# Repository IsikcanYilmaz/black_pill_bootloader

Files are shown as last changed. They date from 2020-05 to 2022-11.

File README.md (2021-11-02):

~ L I G H T  C U B E ~

A "Cube of light" using panels full of WS2812B addressable LEDs, based on an STM32L453.

Current state of the project is:
 - LED panels glued and soldered into forming the 5 sides of the cube.
 - The panels work; STM devboard able to play animations and whatnot.
 - HW design should be done. Gotta order it
 
Need to do:
 - Order it, assemble it.
 - Get the nordic part to work, enable bluetooth. 

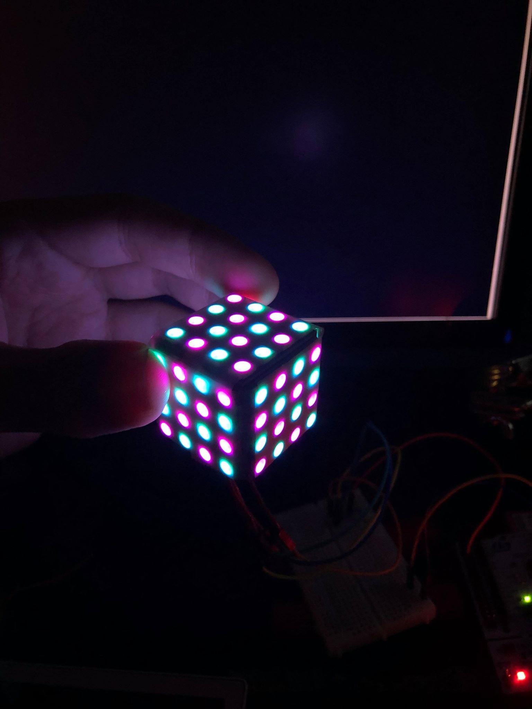
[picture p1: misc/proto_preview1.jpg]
Prototype 1


Prototype demo:
https://imgur.com/a/DEMgBDq

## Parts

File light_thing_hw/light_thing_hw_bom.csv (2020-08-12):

Id | Designator | Package | Quantity | Designation | Reference / name | Supplier | Notes | unit price | multiplier | total
1 | C6,C5 | C_0603_1608Metric_Pad1.05x0.95mm_HandSolder | 2 | 1uF | CL10A105KP8NNNC |  |  | 0.038 | 2 | 0.076
2 | C7,C19,C20 | C_0603_1608Metric_Pad1.05x0.95mm_HandSolder | 3 | 220uF | GRM31CC80G227ME11L |  |  | 1.29 | 3 | 3.87
3 | J5 | PinHeader_1x03_P1.00mm_Vertical | 1 | MIC_CONN | --- |  |  | 0 | 1 | 0
4 | U5A1 | LQFP-64-1EP_10x10mm_P0.5mm_EP6.5x6.5mm | 1 | STM32L452RETx | ?STM32L452RET6? |  |  | 7.1 | 1 | 7.1
5 | C1,C2,C3,C4,C16,C17 | C_0603_1608Metric_Pad1.05x0.95mm_HandSolder | 6 | 0.1uF | ?C0603C104Z3VACTU? |  |  | 0.031 | 6 | 0.186
6 | C8,C10,C14,C18 | C_0603_1608Metric_Pad1.05x0.95mm_HandSolder | 4 | 10uF | ?GRM188R61A106KE69J? |  |  | 0.148 | 4 | 0.592
7 | C9,C11,C13 | C_0603_1608Metric_Pad1.05x0.95mm_HandSolder | 3 | 100nF | C0603C104Z3VACTU |  |  | 0.031 | 3 | 0.093
8 | C12 | C_0603_1608Metric_Pad1.05x0.95mm_HandSolder | 1 | 1nF | ?CC0603KRX7R9BB102? |  |  | 0.1 | 1 | 0.1
9 | C15 | C_0603_1608Metric_Pad1.05x0.95mm_HandSolder | 1 | 2700pF | ?CC0603KRX7R9BB272? |  |  | 0.1 | 1 | 0.1
10 | D1 | D_SOD-323_HandSoldering | 1 | 2.5A, 20V | PMEG4030EP,115? |  |  | 0.43 | 1 | 0.43
11 | D2 | LED_0603_1608Metric_Pad1.05x0.95mm_HandSolder | 1 | GREEN LED | ?LTST-C191KRKT? |  |  | 0.26 | 1 | 0.26
12 | D3 | LED_0603_1608Metric_Pad1.05x0.95mm_HandSolder | 1 | RED LED | ?LTST-C191KRKT? |  |  | 0.26 | 1 | 0.26
13 | J1 | PinHeader_2x05_P1.00mm_Vertical | 1 | CONNECTORS | --- |  |  | 0 | 1 | 0
14 | J2 | Molex_PicoBlade_53261-0271_1x02-1MP_P1.25mm_Horizontal | 1 | Li-Ion Battery | ?0532610271? WM7620CT-ND? |  |  | 0.51 | 1 | 0.51
15 | J3 | PinHeader_2x02_P1.00mm_Vertical | 1 | ADDR_LED_PANEL_1_CONNECTORS | --- |  |  | 0 | 1 | 0
16 | J4 | PinHeader_2x02_P1.00mm_Vertical | 1 | ADDR_LED_PANEL_2_CONNECTORS | --- |  |  | 0 | 1 | 0
17 | L1 | L_0603_1608Metric_Pad1.05x0.95mm_HandSolder | 1 | 10uH, 2.5A | ?CBMF1608T100K? |  | this needs to change :( | 2.59333 | 1 | 2.59333
18 | Q1 | SOT-23 | 1 | MMBF170 | ?MMBF170LT1G? |  |  | 0.28 | 1 | 0.28
19 | R1,R2,R14,R17 | R_0603_1608Metric_Pad1.05x0.95mm_HandSolder | 4 | 1k | ?RC0603JR-071KL? |  |  | 0.018 | 4 | 0.072
20 | R3 | R_0603_1608Metric_Pad1.05x0.95mm_HandSolder | 1 | 30.1k | ?RT0603BRD0730K1L? |  |  | 0.35 | 1 | 0.35
21 | R4 | R_0603_1608Metric_Pad1.05x0.95mm_HandSolder | 1 | 10k | ?RC0603FR-0710KL? |  |  | 0.022 | 1 | 0.022
22 | R5 | R_0603_1608Metric_Pad1.05x0.95mm_HandSolder | 1 | 10K | ?RC0603FR-0710KL? |  |  | 0.022 | 1 | 0.022
23 | R6,R10,R11,R12,R13 | R_0603_1608Metric_Pad1.05x0.95mm_HandSolder | 5 | 4.7k | ?RC0603JR-074K7L? |  |  | 0.018 | 5 | 0.09
24 | R7 | R_0603_1608Metric_Pad1.05x0.95mm_HandSolder | 1 | 100 | ?RC0603FR-07100RL? |  |  | 0.022 | 1 | 0.022
25 | R8,R9 | R_0603_1608Metric_Pad1.05x0.95mm_HandSolder | 2 | 510 | ?RC0603FR-07510RL? |  |  | 0.022 | 2 | 0.044
26 | R15 | R_0603_1608Metric_Pad1.05x0.95mm_HandSolder | 1 | 2k | ?RC0603FR-072KL? |  |  | 0.022 | 1 | 0.022
27 | R16 | R_0603_1608Metric_Pad1.05x0.95mm_HandSolder | 1 | 357 | ?RC0603FR-07357RL? |  |  | 0.022 | 1 | 0.022
28 | SW1 | SW_SPST_B3U-3000P | 1 | ST_USER_BUTTON1 | EVP-AKE31A? |  |  | 0.61 | 1 | 0.61
29 | U1 | BC832-BC832_3d1 | 1 | BC832-V1 | 1914-1017-1-ND |  |  | 11.66 | 1 | 11.66
30 | U3 | MCP73833T-FCIUN-SMD | 1 | MCP73833T-FCI_UN | MCP73833T-FCI/UN? |  |  | 0.85 | 1 | 0.85
31 | U4 | SOT-23-5 | 1 | LMR62421XMF | LMR62421XMF/NOPB |  |  | 1.95 | 1 | 1.95
32 | U5 | LP38511MRX-ADJ_NOPB | 1 | LP38511MRX-ADJ_NOPB | LP38511MRX-ADJ/NOPB? |  |  | 1.77 | 1 | 1.77
33 | USB_MICRO_CONN1 | USB_Micro-B_Molex_47346-0001 | 1 | USB_OTG | ?0473461001? / WM11228CT-ND? |  |  | 0.91 | 1 | 0.91
34 | TP1,TP2 | TestPoint_Pad_D1.0mm | 2 | TestPoint | --- |  |  | 0 | 2 | 0
35 | U2 | LGA-14_3x2.5mm_P0.5mm_LayoutBorder3x4y_modded | 1 | LSM6DS3 | LSM6DS3TR? |  |  | 3.06 | 1 | 3.06
36 | R18 | R_0603_1608Metric_Pad1.05x0.95mm_HandSolder | 1 | 300 | ?RC0603FR-07300RL? |  |  | 0.022 | 1 | 0.022
37 | Q2 | SOT-23 | 1 | BSS83P | BSS83PH6327XTSA1 |  |  | 0.41 | 1 | 0.41
38 | SW2 | SW_SPST_EVPBF | 1 | ST_RESET_BUTTON |  |  |  | 0 | 1 | 0
 |  |  |  |  |  |  |  |  |  | 38.35833

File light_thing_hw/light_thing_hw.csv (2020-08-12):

Id | Designator | Package | Quantity | Designation | Supplier and ref
1 | U5A1 | LQFP-64-1EP_10x10mm_P0.5mm_EP6.5x6.5mm | 1 | STM32L452RETx
2 | C1,C2,C3,C4,C16,C17 | C_0603_1608Metric_Pad1.05x0.95mm_HandSolder | 6 | 0.1uF
3 | C5,C6 | C_0603_1608Metric_Pad1.05x0.95mm_HandSolder | 2 | 1uF
4 | C7 | C_0603_1608Metric_Pad1.05x0.95mm_HandSolder | 1 | C_Small
5 | C8,C10,C14,C18 | C_0603_1608Metric_Pad1.05x0.95mm_HandSolder | 4 | 10uF
6 | C9,C11,C13 | C_0603_1608Metric_Pad1.05x0.95mm_HandSolder | 3 | 100nF
7 | C12 | C_0603_1608Metric_Pad1.05x0.95mm_HandSolder | 1 | 1nF
8 | C15 | C_0603_1608Metric_Pad1.05x0.95mm_HandSolder | 1 | 2700pF
9 | D1 | D_SOD-323_HandSoldering | 1 | 2.5A, 20V
10 | D2 | LED_0603_1608Metric_Pad1.05x0.95mm_HandSolder | 1 | GREEN LED
11 | D3 | LED_0603_1608Metric_Pad1.05x0.95mm_HandSolder | 1 | RED LED
12 | J1 | PinHeader_2x05_P1.00mm_Vertical | 1 | CONNECTORS
13 | J2 | Molex_PicoBlade_53261-0271_1x02-1MP_P1.25mm_Horizontal | 1 | Li-Ion Battery
14 | J3 | PinHeader_2x02_P1.00mm_Vertical | 1 | ADDR_LED_PANEL_1_CONNECTORS
15 | J4 | PinHeader_2x02_P1.00mm_Vertical | 1 | ADDR_LED_PANEL_2_CONNECTORS
16 | L1 | L_0603_1608Metric_Pad1.05x0.95mm_HandSolder | 1 | 10uH, 2.5A
17 | Q1 | SOT-23 | 1 | MMBF170
18 | R1,R2,R14,R17 | R_0603_1608Metric_Pad1.05x0.95mm_HandSolder | 4 | 1k
19 | R3 | R_0603_1608Metric_Pad1.05x0.95mm_HandSolder | 1 | 30.1k
20 | R4 | R_0603_1608Metric_Pad1.05x0.95mm_HandSolder | 1 | 10k
21 | R5 | R_0603_1608Metric_Pad1.05x0.95mm_HandSolder | 1 | 10K
22 | R6,R10,R11,R12,R13 | R_0603_1608Metric_Pad1.05x0.95mm_HandSolder | 5 | 4.7k
23 | R7 | R_0603_1608Metric_Pad1.05x0.95mm_HandSolder | 1 | 100
24 | R8,R9 | R_0603_1608Metric_Pad1.05x0.95mm_HandSolder | 2 | 510
25 | R15 | R_0603_1608Metric_Pad1.05x0.95mm_HandSolder | 1 | 2k
26 | R16 | R_0603_1608Metric_Pad1.05x0.95mm_HandSolder | 1 | 357
27 | SW1 | SW_SPST_B3U-3000P | 1 | ST_USER_BUTTON1
28 | SW2 | SW_SPST_CK_RS282G05A3 | 1 | ST_RESET_BUTTON
29 | U1 | BC832-BC832_3d1 | 1 | BC832-V1
30 | U3 | MCP73833T-FCIUN-SMD | 1 | MCP73833T-FCI_UN
31 | U4 | SOT-23-5 | 1 | LMR62421XMF
32 | U5 | LP38511MRX-ADJ_NOPB | 1 | LP38511MRX-ADJ_NOPB
33 | USB_MICRO_CONN1 | USB_Micro-B_Molex_47346-0001 | 1 | USB_OTG
34 | 3v3,gnd | TestPoint_Pad_D1.0mm | 2 | TestPoint
35 | U2 | LGA-14_3x2.5mm_P0.5mm_LayoutBorder3x4y_modded | 1 | LSM6DS3

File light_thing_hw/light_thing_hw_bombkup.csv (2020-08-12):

Id | Designator | Package | Quantity | Designation | Reference / name | Supplier
1 | C6,C5 | C_0603_1608Metric_Pad1.05x0.95mm_HandSolder | 2 | 1uF | ‎CL10A105KP8NNNC‎
2 | C7 | C_0603_1608Metric_Pad1.05x0.95mm_HandSolder | 1 | 1000uF | ‎GRM31CC80G227ME11L‎
3 | J5 | PinHeader_1x03_P1.00mm_Vertical | 1 | MIC_CONN
4 | U5A1 | LQFP-64-1EP_10x10mm_P0.5mm_EP6.5x6.5mm | 1 | STM32L452RETx | ‎STM32L452RET6‎
5 | C1,C2,C3,C4,C16,C17 | C_0603_1608Metric_Pad1.05x0.95mm_HandSolder | 6 | 0.1uF | ‎C0603C104Z3VACTU‎
6 | C8,C10,C14,C18 | C_0603_1608Metric_Pad1.05x0.95mm_HandSolder | 4 | 10uF | ‎GRM188R61A106KE69J‎
7 | C9,C11,C13 | C_0603_1608Metric_Pad1.05x0.95mm_HandSolder | 3 | 100nF | C0603C104Z3VACTU
8 | C12 | C_0603_1608Metric_Pad1.05x0.95mm_HandSolder | 1 | 1nF | ‎CC0603KRX7R9BB102‎
9 | C15 | C_0603_1608Metric_Pad1.05x0.95mm_HandSolder | 1 | 2700pF | ‎CC0603KRX7R9BB272‎
10 | D1 | D_SOD-323_HandSoldering | 1 | 2.5A, 20V
11 | D2 | LED_0603_1608Metric_Pad1.05x0.95mm_HandSolder | 1 | GREEN LED
12 | D3 | LED_0603_1608Metric_Pad1.05x0.95mm_HandSolder | 1 | RED LED
13 | J1 | PinHeader_2x05_P1.00mm_Vertical | 1 | CONNECTORS
14 | J2 | Molex_PicoBlade_53261-0271_1x02-1MP_P1.25mm_Horizontal | 1 | Li-Ion Battery
15 | J3 | PinHeader_2x02_P1.00mm_Vertical | 1 | ADDR_LED_PANEL_1_CONNECTORS
16 | J4 | PinHeader_2x02_P1.00mm_Vertical | 1 | ADDR_LED_PANEL_2_CONNECTORS
17 | L1 | L_0603_1608Metric_Pad1.05x0.95mm_HandSolder | 1 | 10uH, 2.5A
18 | Q1 | SOT-23 | 1 | MMBF170 | ‎MMBF170LT1G‎
19 | R1,R2,R14,R17 | R_0603_1608Metric_Pad1.05x0.95mm_HandSolder | 4 | 1k
20 | R3 | R_0603_1608Metric_Pad1.05x0.95mm_HandSolder | 1 | 30.1k
21 | R4 | R_0603_1608Metric_Pad1.05x0.95mm_HandSolder | 1 | 10k
22 | R5 | R_0603_1608Metric_Pad1.05x0.95mm_HandSolder | 1 | 10K
23 | R6,R10,R11,R12,R13 | R_0603_1608Metric_Pad1.05x0.95mm_HandSolder | 5 | 4.7k
24 | R7 | R_0603_1608Metric_Pad1.05x0.95mm_HandSolder | 1 | 100
25 | R8,R9 | R_0603_1608Metric_Pad1.05x0.95mm_HandSolder | 2 | 510
26 | R15 | R_0603_1608Metric_Pad1.05x0.95mm_HandSolder | 1 | 2k
27 | R16 | R_0603_1608Metric_Pad1.05x0.95mm_HandSolder | 1 | 357
28 | SW1 | SW_SPST_B3U-3000P | 1 | ST_USER_BUTTON1 | EVP-AKE31A‎
29 | U1 | BC832-BC832_3d1 | 1 | BC832-V1
30 | U3 | MCP73833T-FCIUN-SMD | 1 | MCP73833T-FCI_UN | MCP73833T-FCI/UN‎ | digikey
31 | U4 | SOT-23-5 | 1 | LMR62421XMF | LMR62421XMF/NOPB | digikey
32 | U5 | LP38511MRX-ADJ_NOPB | 1 | LP38511MRX-ADJ_NOPB | LP38511MRX-ADJ/NOPB‎
33 | USB_MICRO_CONN1 | USB_Micro-B_Molex_47346-0001 | 1 | USB_OTG | ‎0473461001‎ / WM11228CT-ND‎
34 | TP1,TP2 | TestPoint_Pad_D1.0mm | 2 | TestPoint
35 | U2 | LGA-14_3x2.5mm_P0.5mm_LayoutBorder3x4y_modded | 1 | LSM6DS3 | ‎LSM6DS3TR‎
36 | R18 | R_0603_1608Metric_Pad1.05x0.95mm_HandSolder | 1 | 300
37 | Q2 | SOT-23 | 1 | BSS83P | ‎BSS83PH6327XTSA1‎
38 | SW2 | SW_SPST_EVPBF | 1 | ST_RESET_BUTTON

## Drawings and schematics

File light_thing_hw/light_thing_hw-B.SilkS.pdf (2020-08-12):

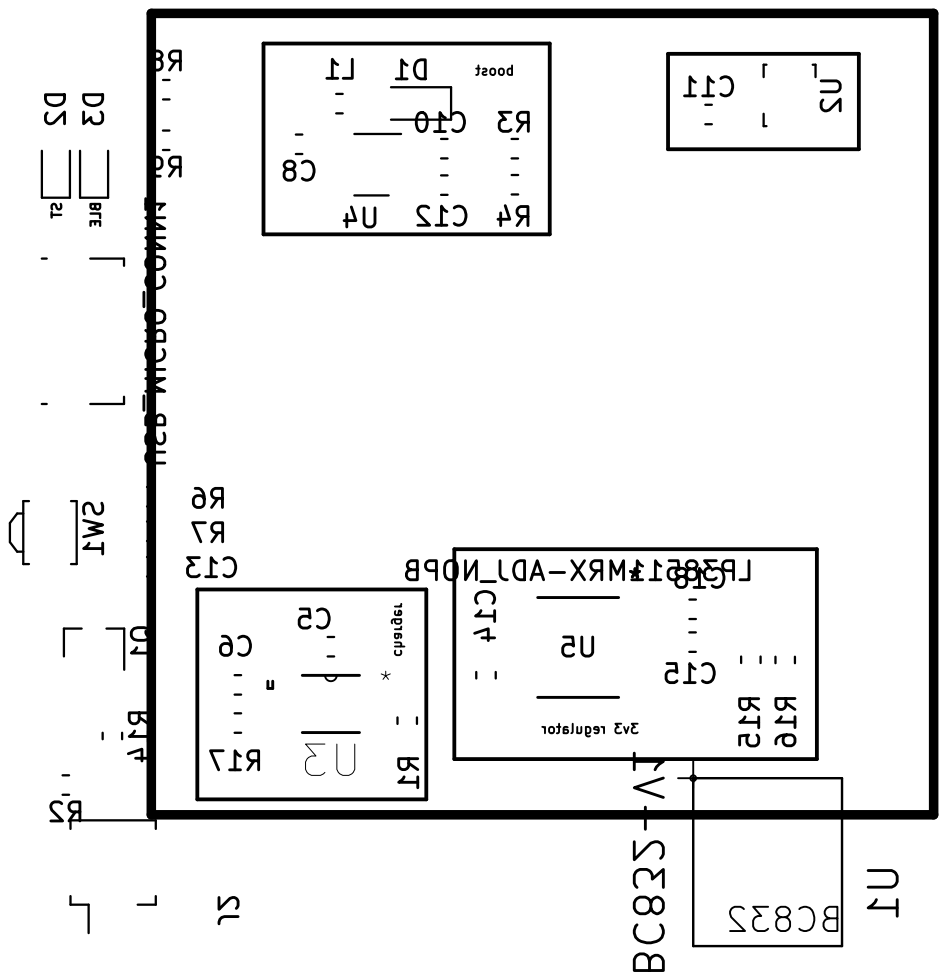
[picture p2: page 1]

charger boost 3v3 regulator STBLE C5 C6 C8 C10 C11 C12 C13 C14 C15 C18 D1 D2 D3 J2 L1 Q1 R1 R2 R3 R4 R6 R7 R8 R9R14 R15 R16 R17 SW1 U1 BC832-V1 BC832 U3

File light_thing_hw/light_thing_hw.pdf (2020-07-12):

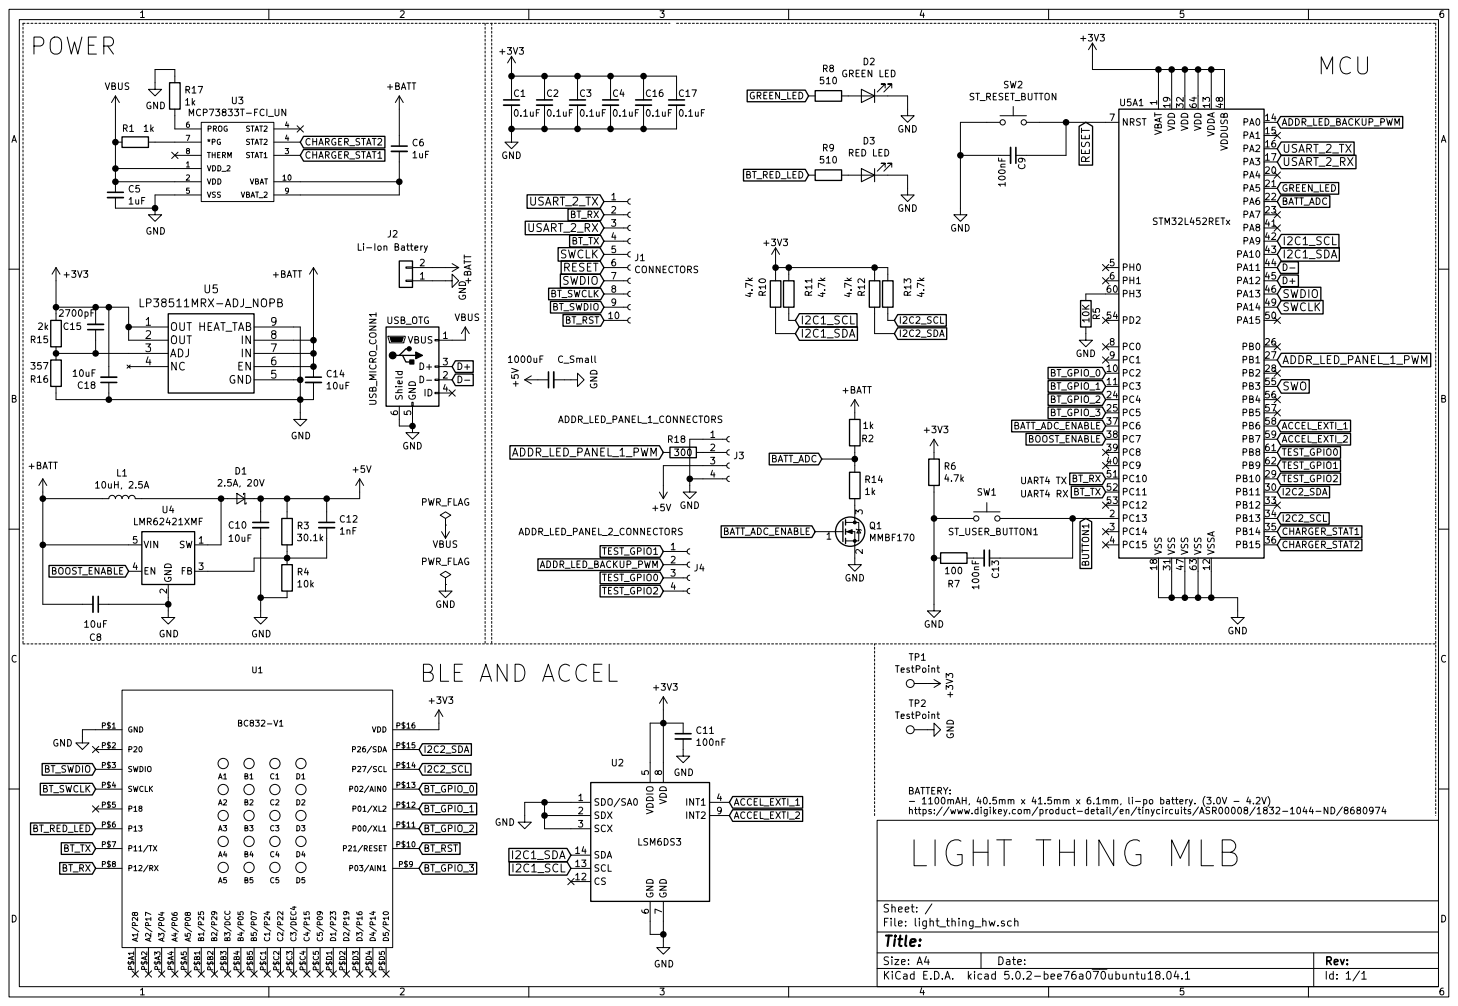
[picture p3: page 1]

1 VDD 19 VDD 32 VDD 64 VDDA 13 VDDUSB 48 VSS 18 VSS 31 VSS 47 VSS 63 VSSA 12 U5A1 STM32L452RETx BATT_ADC

BATTERY: - 1100mAH, 40.5mm x 41.5mm x 6.1mm, li-po battery. (3.0V - 4.2V)
LIGHT THING MLB

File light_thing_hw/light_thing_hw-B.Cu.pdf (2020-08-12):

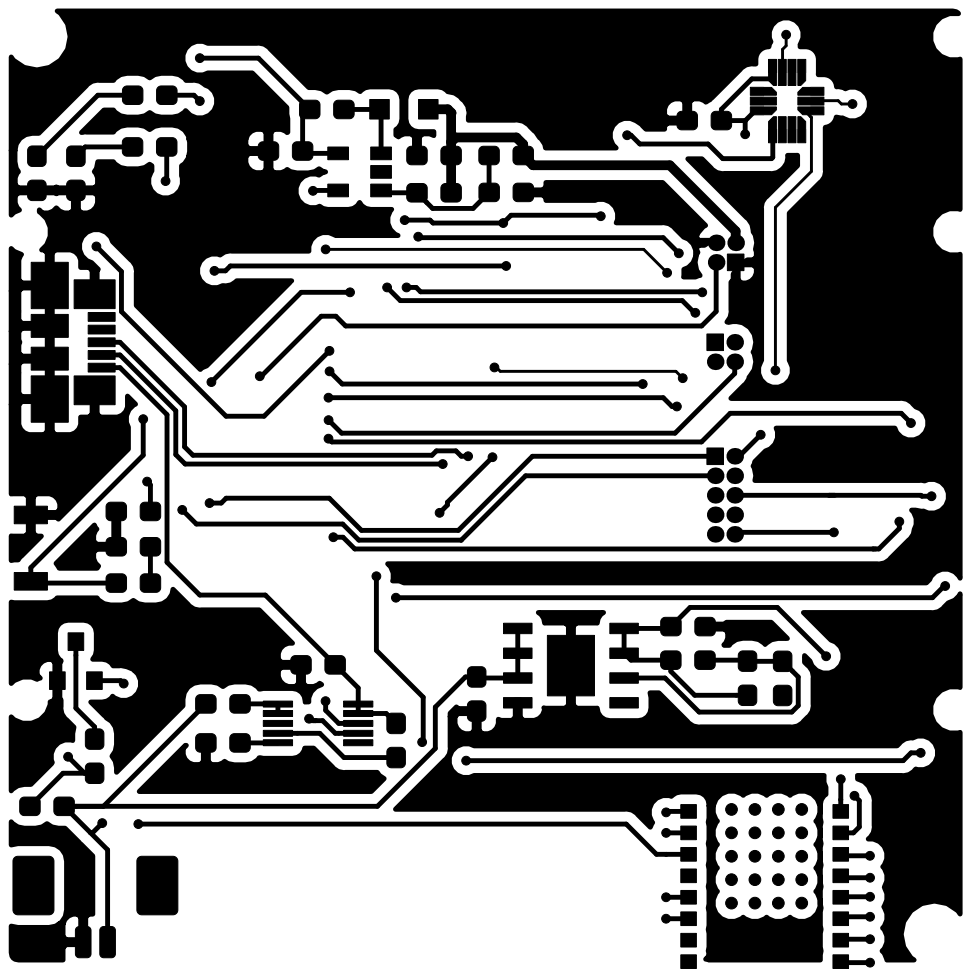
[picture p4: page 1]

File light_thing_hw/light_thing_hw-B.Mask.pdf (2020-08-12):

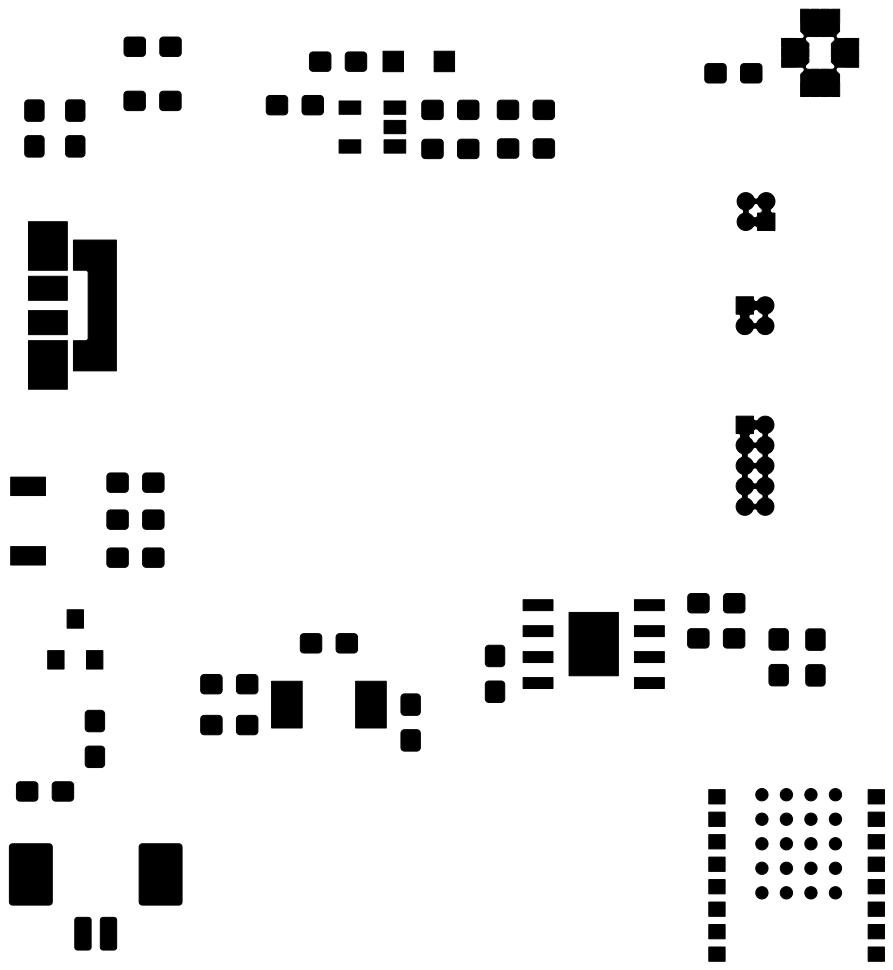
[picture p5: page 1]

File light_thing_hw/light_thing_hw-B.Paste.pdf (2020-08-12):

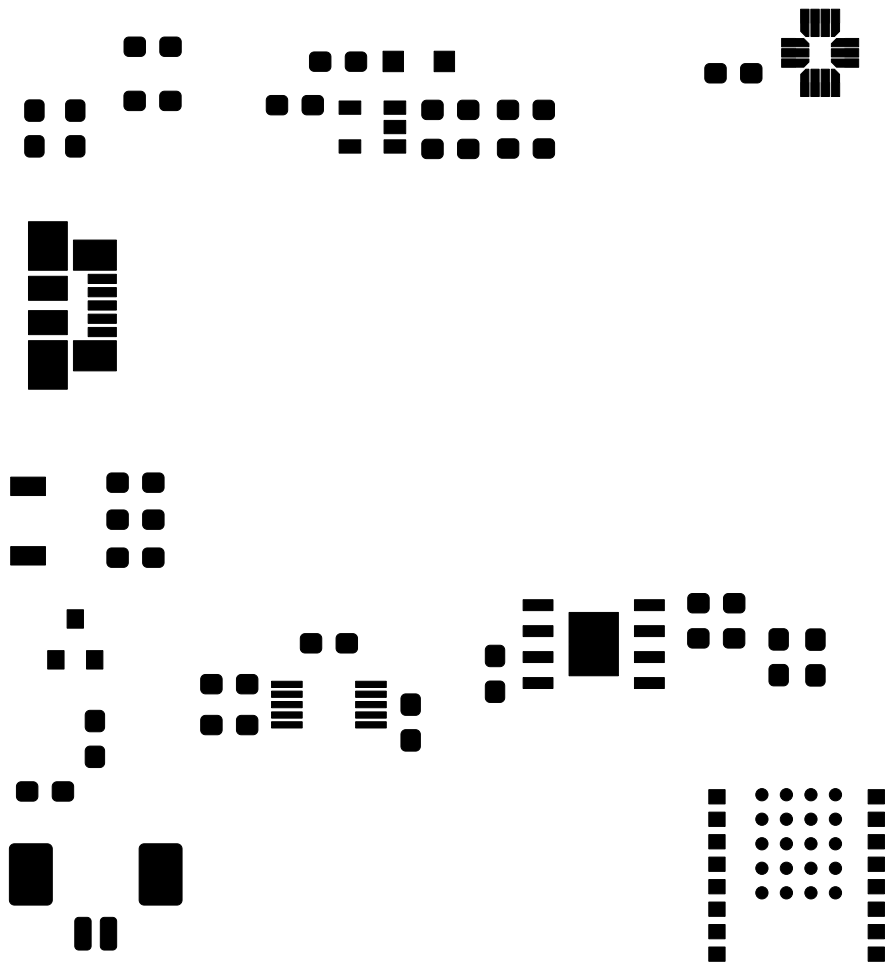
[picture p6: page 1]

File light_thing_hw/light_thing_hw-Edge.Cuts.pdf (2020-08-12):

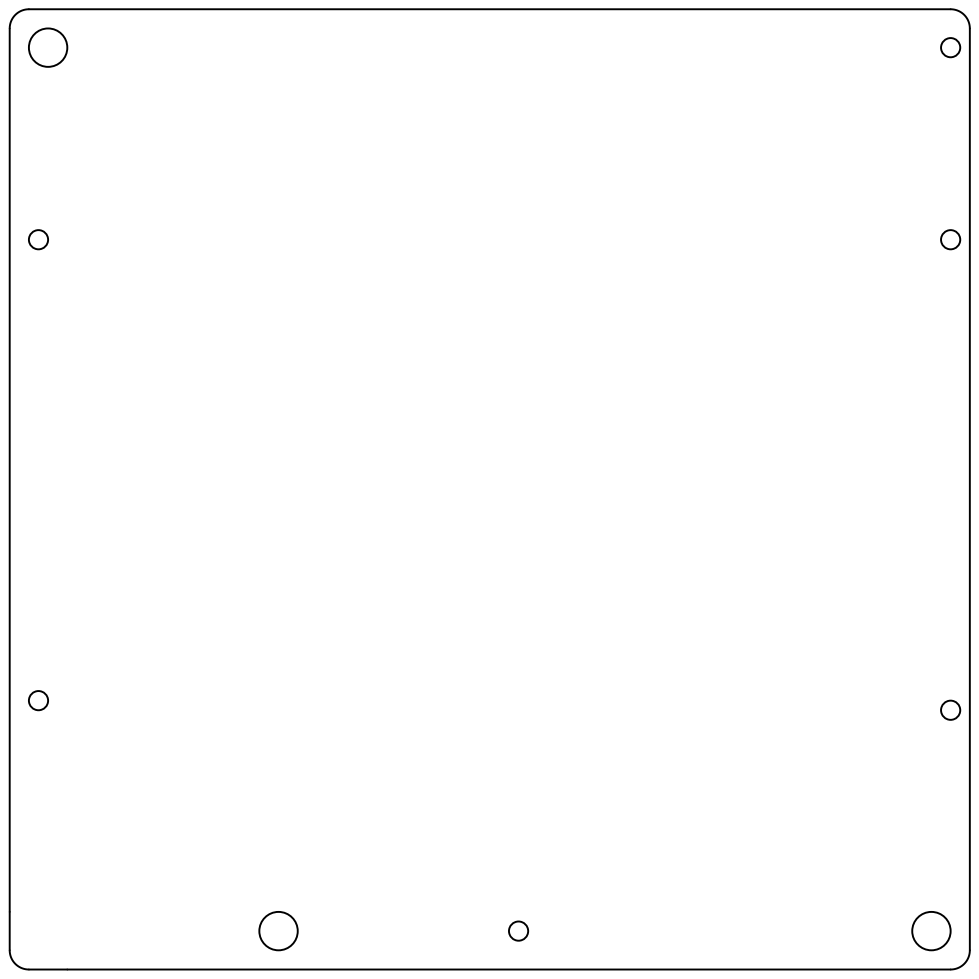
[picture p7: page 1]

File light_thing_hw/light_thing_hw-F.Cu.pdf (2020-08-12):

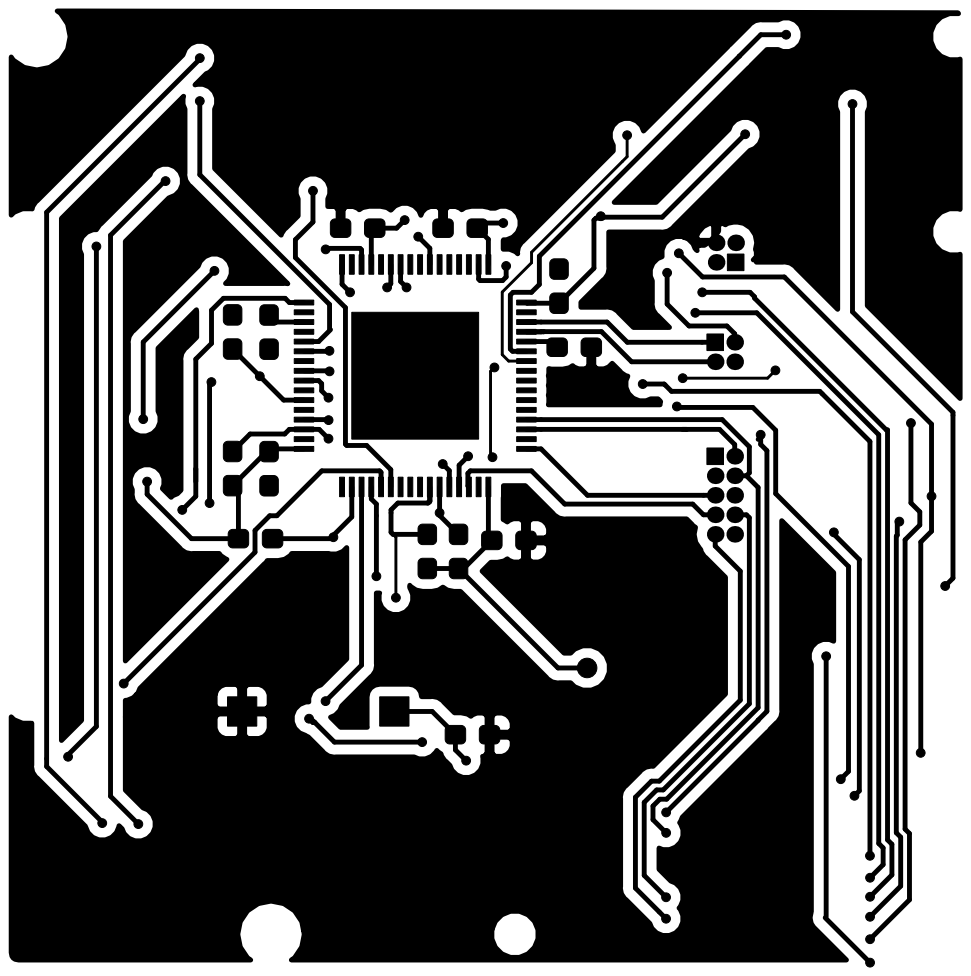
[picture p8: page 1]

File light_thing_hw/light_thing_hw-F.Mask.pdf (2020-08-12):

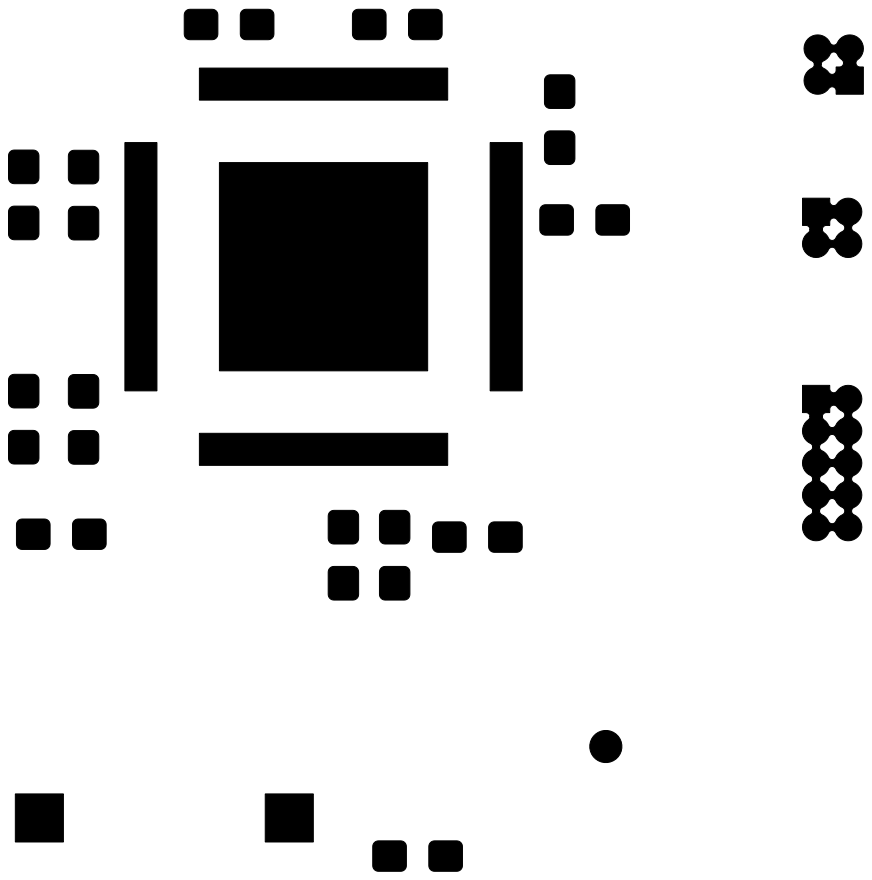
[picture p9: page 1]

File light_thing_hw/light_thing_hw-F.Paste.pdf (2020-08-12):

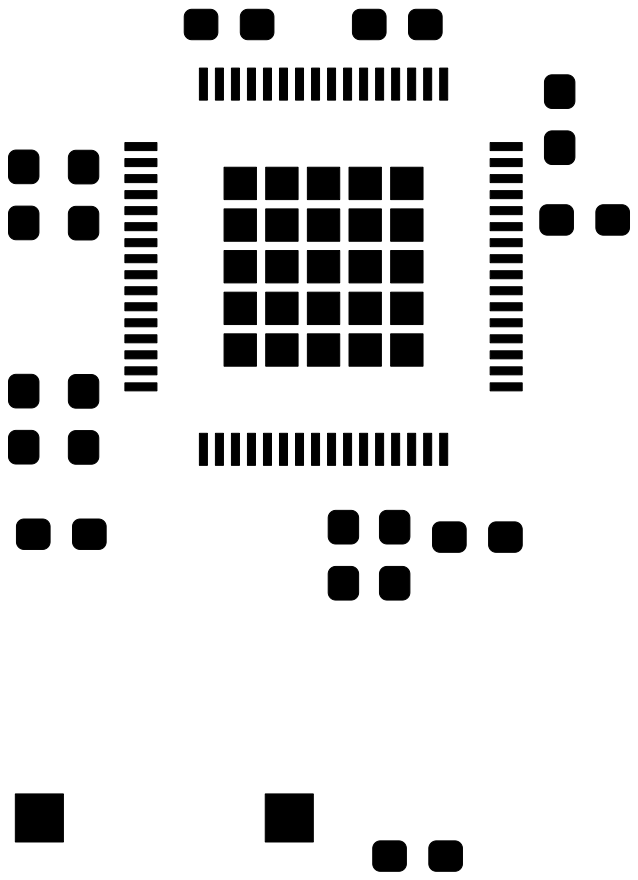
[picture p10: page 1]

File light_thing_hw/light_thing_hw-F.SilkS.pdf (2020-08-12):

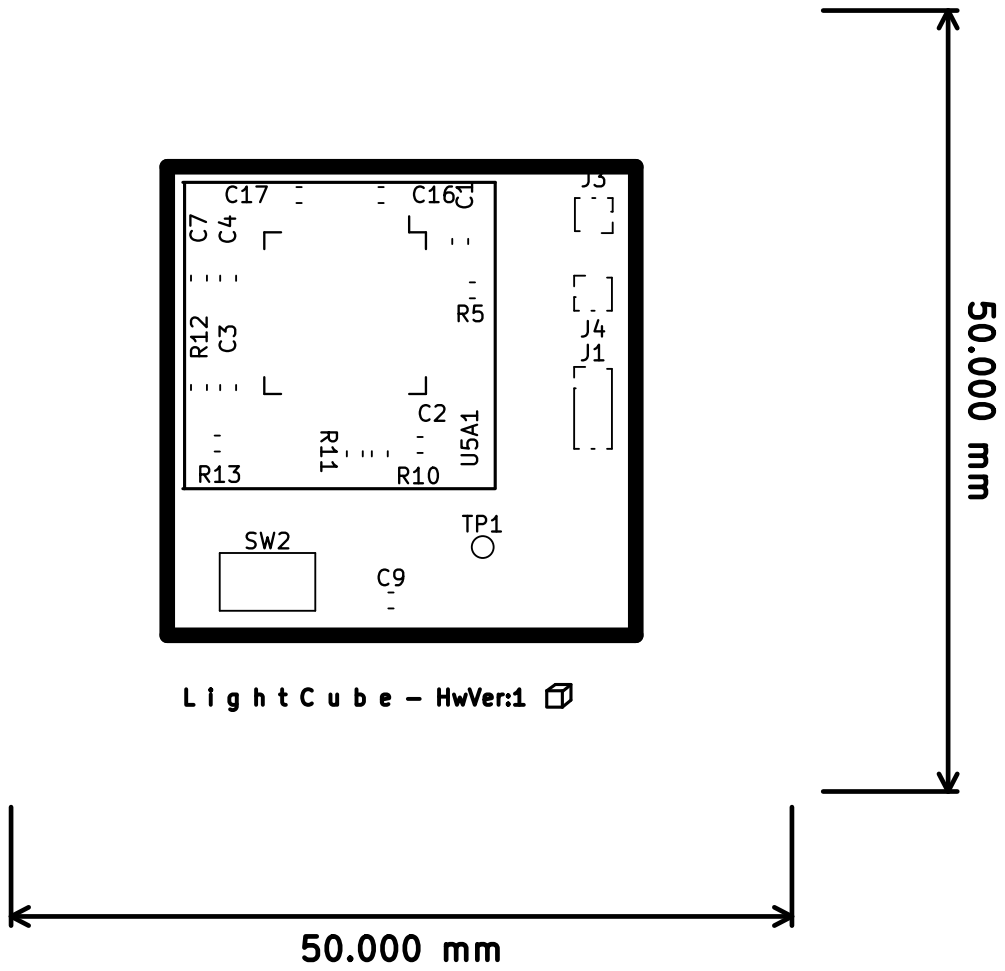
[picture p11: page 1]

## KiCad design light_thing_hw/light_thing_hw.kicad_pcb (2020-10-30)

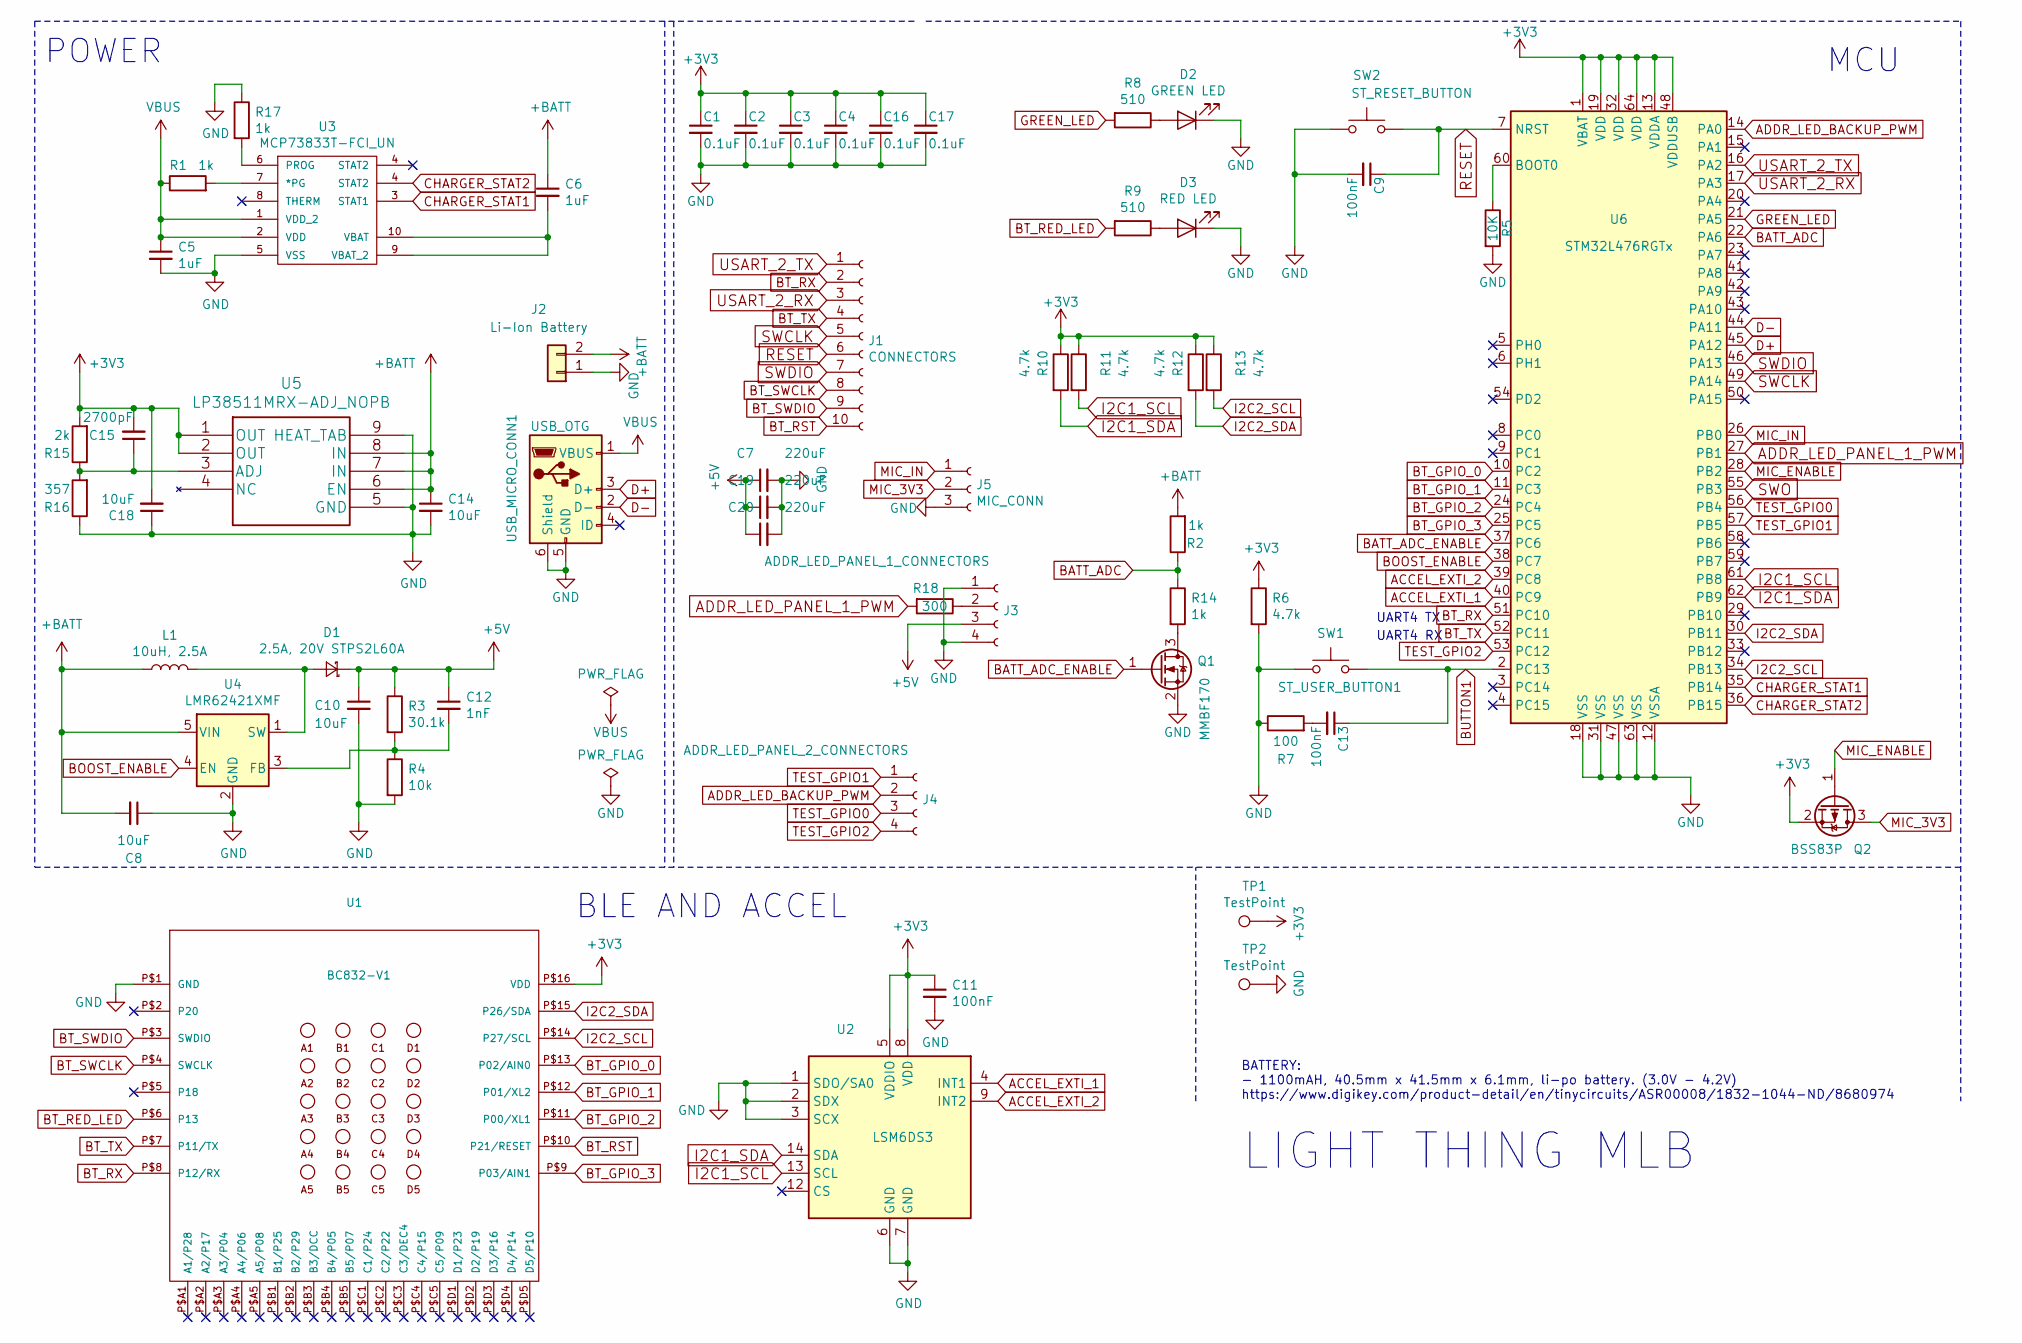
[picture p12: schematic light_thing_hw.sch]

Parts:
C1, C2, C3, C4, C16, C17: 0.1uF; C_0603_1608Metric_Pad1.05x0.95mm_HandSolder
C5, C6: 1uF; C_0603_1608Metric_Pad1.05x0.95mm_HandSolder
C7, C19, C20: 220uF; C_0603_1608Metric_Pad1.05x0.95mm_HandSolder
C8, C10, C14, C18: 10uF; C_0603_1608Metric_Pad1.05x0.95mm_HandSolder
C9, C11, C13: 100nF; C_0603_1608Metric_Pad1.05x0.95mm_HandSolder
C12: 1nF; C_0603_1608Metric_Pad1.05x0.95mm_HandSolder
C15: 2700pF; C_0603_1608Metric_Pad1.05x0.95mm_HandSolder
D1: 2.5A, 20V STPS2L60A; D_SMA
D2: GREEN LED; LED_0603_1608Metric_Pad1.05x0.95mm_HandSolder
D3: RED LED; LED_0603_1608Metric_Pad1.05x0.95mm_HandSolder
J1: CONNECTORS; PinHeader_2x05_P1.00mm_Vertical
J2: Li-Ion Battery; Molex_PicoBlade_53261-0271_1x02-1MP_P1.25mm_Horizontal
J3: ADDR_LED_PANEL_1_CONNECTORS; PinHeader_2x02_P1.00mm_Vertical
J4: ADDR_LED_PANEL_2_CONNECTORS; PinHeader_2x02_P1.00mm_Vertical
J5: MIC_CONN; PinHeader_1x03_P1.00mm_Vertical
L1: 10uH, 2.5A; L_0603_1608Metric_Pad1.05x0.95mm_HandSolder
Q1: MMBF170; SOT-23
Q2: BSS83P; SOT-23
R1, R2, R14, R17: 1k; R_0603_1608Metric_Pad1.05x0.95mm_HandSolder
R3: 30.1k; R_0603_1608Metric_Pad1.05x0.95mm_HandSolder
R4: 10k; R_0603_1608Metric_Pad1.05x0.95mm_HandSolder
R5: 10K; R_0603_1608Metric_Pad1.05x0.95mm_HandSolder
R6, R10, R11, R12, R13: 4.7k; R_0603_1608Metric_Pad1.05x0.95mm_HandSolder
R7: 100; R_0603_1608Metric_Pad1.05x0.95mm_HandSolder
R8, R9: 510; R_0603_1608Metric_Pad1.05x0.95mm_HandSolder
R15: 2k; R_0603_1608Metric_Pad1.05x0.95mm_HandSolder
R16: 357; R_0603_1608Metric_Pad1.05x0.95mm_HandSolder
R18: 300; R_0603_1608Metric_Pad1.05x0.95mm_HandSolder
SW1: ST_USER_BUTTON1; SW_SPST_B3U-3000P
SW2: ST_RESET_BUTTON; SW_SPST_PTS645
TP1, TP2: TestPoint; TestPoint_Pad_D1.0mm
U1: BC832-V1; BC832-BC832_3d1
U2: LSM6DS3; LGA-14_3x2.5mm_P0.5mm_LayoutBorder3x4y
U3: MCP73833T-FCI_UN; MCP73833T-FCIUN-SMD
U4: LMR62421XMF; SOT-23-5
U5: LP38511MRX-ADJ_NOPB
U6: STM32L476RGTx; LQFP-64_10x10mm_P0.5mm
USB_MICRO_CONN1: USB_OTG; USB_Micro-B_Molex_47346-0001

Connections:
+3V3: C1.1, C2.1, C3.1, C4.1, C11.1, C15.2, C16.1, C17.1, C18.2, Q2.2 (S), R6.1, R10.1, R11.1, R12.1, R13.1, R15.2, TP1.1, U1.P$16 (VDD), U2.5 (VDDIO), U2.8 (VDD), U5.1 (OUT), U5.2 (OUT), U6.1 (VBAT), U6.13 (VDDA), U6.19 (VDD), U6.32 (VDD), U6.48 (VDDUSB), U6.64 (VDD)
+5V: C7.1, C10.1, C12.1, C19.1, C20.1, D1.1 (K), J3.3, R3.1
+BATT: C6.1, C8.2, C14.1, J2.2, L1.1, R2.2, U4.5 (VIN), U5.6 (EN), U5.7 (IN), U5.8 (IN)
ACCEL_EXTI_1: U2.4 (INT1), U6.40 (PC9)
ACCEL_EXTI_2: U2.9 (INT2), U6.39 (PC8)
ADDR_LED_BACKUP_PWM: J4.2, U6.14 (PA0)
ADDR_LED_PANEL_1_PWM: R18.2, U6.27 (PB1)
BATT_ADC: R2.1, R14.1, U6.22 (PA6)
BATT_ADC_ENABLE: Q1.1 (G), U6.37 (PC6)
BOOST_ENABLE: U4.4 (EN), U6.38 (PC7)
BT_GPIO_0: U1.P$13 (P02/AIN0), U6.10 (PC2)
BT_GPIO_1: U1.P$12 (P01/XL2), U6.11 (PC3)
BT_GPIO_2: U1.P$11 (P00/XL1), U6.24 (PC4)
BT_GPIO_3: U1.P$9 (P03/AIN1), U6.25 (PC5)
BT_RED_LED: R9.2, U1.P$6 (P13)
BT_RST: J1.10, U1.P$10 (P21/RESET)
BT_RX: J1.2, U1.P$8 (P12/RX), U6.51 (PC10)
BT_SWCLK: J1.8, U1.P$4 (SWCLK)
BT_SWDIO: J1.9, U1.P$3 (SWDIO)
BT_TX: J1.4, U1.P$7 (P11/TX), U6.52 (PC11)
BUTTON1: C13.1, SW1.2, U6.2 (PC13)
CHARGER_STAT1: U3.3 (STAT1), U6.35 (PB14)
CHARGER_STAT2: U3.4 (STAT2), U6.36 (PB15)
D+: U6.45 (PA12), USB_MICRO_CONN1.3 (D+)
D-: U6.44 (PA11), USB_MICRO_CONN1.2 (D-)
GND: C1.2, C2.2, C3.2, C4.2, C5.2, C7.2, C8.1, C9.2, C10.2, C11.2, C14.2, C16.2, C17.2, C18.1, C19.2, C20.2, D2.1 (K), D3.1 (K), J2.1, J3.1, J3.4, J5.3, Q1.2 (S), R4.2, R5.2, R6.2, R7.1, R16.1, R17.1, SW1.1, SW2.1, TP2.1, U1.P$1 (GND), U2.1 (SDO/SA0), U2.2 (SDX), U2.3 (SCX), U2.6 (GND), U2.7 (GND), U3.5 (VSS), U4.2 (GND), U5.5 (GND), U5.9 (HEAT_TAB), U6.12 (VSSA), U6.18 (VSS), U6.31 (VSS), U6.47 (VSS), U6.63 (VSS), USB_MICRO_CONN1.5 (GND), USB_MICRO_CONN1.6 (Shield)
GREEN_LED: R8.2, U6.21 (PA5)
I2C1_SCL: R11.2, U2.13 (SCL), U6.61 (PB8)
I2C1_SDA: R10.2, U2.14 (SDA), U6.62 (PB9)
I2C2_SCL: R13.2, U1.P$14 (P27/SCL), U6.34 (PB13)
I2C2_SDA: R12.2, U1.P$15 (P26/SDA), U6.30 (PB11)
MIC_3V3: J5.2, Q2.3 (D)
MIC_ENABLE: Q2.1 (G), U6.28 (PB2)
MIC_IN: J5.1, U6.26 (PB0)
unnamed: C6.2, U3.9 (VBAT_2), U3.10 (VBAT)
unnamed: C12.2, R3.2, R4.1, U4.3 (FB)
unnamed: C13.2, R7.2
unnamed: C15.1, R15.1, R16.2, U5.3 (ADJ)
unnamed: D1.2 (A), L1.2, U4.1 (SW)
unnamed: D2.2 (A), R8.1
unnamed: D3.2 (A), R9.1
unnamed: J3.2, R18.1
unnamed: Q1.3 (D), R14.2
unnamed: R1.2, U3.7 (*PG)
unnamed: R5.1, U6.60 (BOOT0)
unnamed: R17.2, U3.6 (PROG)
RESET: C9.1, J1.6, SW2.2, U6.7 (NRST)
SWCLK: J1.5, U6.49 (PA14)
SWDIO: J1.7, U6.46 (PA13)
SWO: U6.55 (PB3)
TEST_GPIO0: J4.3, U6.56 (PB4)
TEST_GPIO1: J4.1, U6.57 (PB5)
TEST_GPIO2: J4.4, U6.53 (PC12)
USART_2_RX: J1.3, U6.17 (PA3)
USART_2_TX: J1.1, U6.16 (PA2)
VBUS: C5.1, R1.1, U3.1 (VDD_2), U3.2 (VDD), USB_MICRO_CONN1.1 (VBUS)

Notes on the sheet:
LIGHT THING MLB
MCU
POWER
BLE AND ACCEL
BATTERY: - 1100mAH, 40.5mm x 41.5mm x 6.1mm, li-po battery. (3.0V - 4.2V) https://www.digikey.com/product-detail/en/tinycircuits/ASR00008/1832-1044-ND/8680974
UART4 TX
UART4 RX

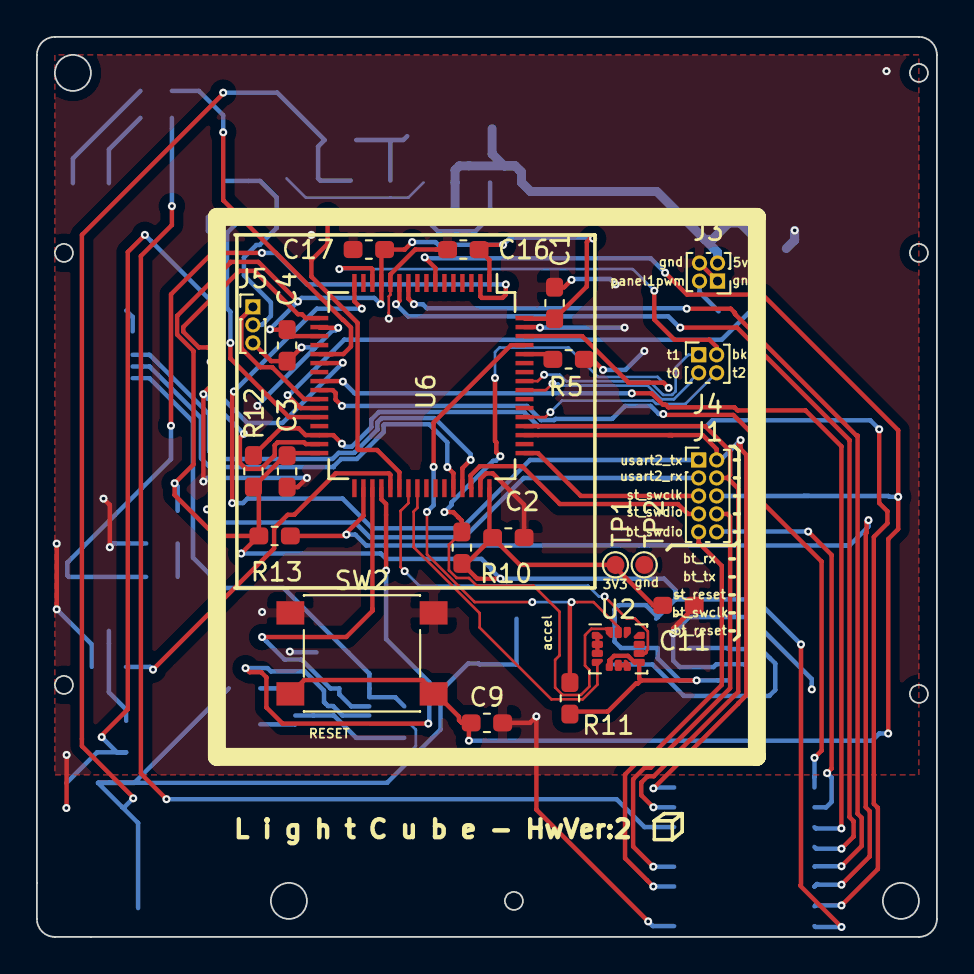
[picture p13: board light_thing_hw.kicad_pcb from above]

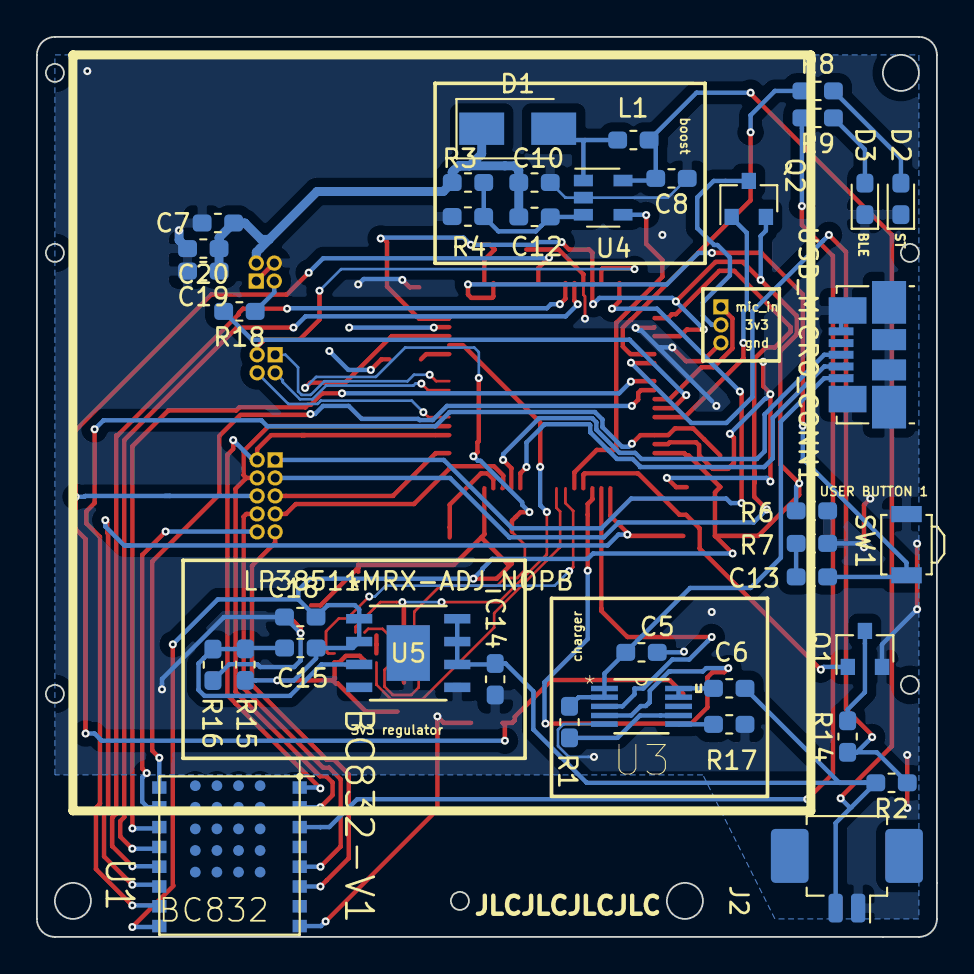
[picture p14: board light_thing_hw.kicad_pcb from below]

Board: 2 copper layers, 50.0 x 50.0 mm, 60 parts (38 on the bottom side), 55 nets.

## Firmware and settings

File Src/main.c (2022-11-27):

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
/* Includes ------------------------------------------------------------------*/
#include "main.h"
#include "adc.h"
#include "dma.h"
#include "i2c.h"
#include "tim.h"
#include "usart.h"
#include "gpio.h"

/* USER CODE BEGIN Includes */
#include "addressable_led_driver.h"
#include "addressable_led_manager.h"
#include "sw_timers.h"
#include "geometry.h"
#include "dbg_uart.h"
/* USER CODE END Includes */


void SystemClock_Config(void);
/**
  * @brief  The application entry point.
  * @retval int
  */
int main(void)
{
  /* MCU Configuration--------------------------------------------------------*/

  /* Reset of all peripherals, Initializes the Flash interface and the Systick. */
  HAL_Init();

  /* Configure the system clock */
  SystemClock_Config();

  /* Initialize all configured peripherals */
  MX_GPIO_Init();
  MX_DMA_Init();
  MX_TIM2_Init();
  MX_TIM3_Init();
  MX_USART2_UART_Init();
  MX_ADC1_Init();
  MX_I2C1_Init();
  MX_I2C2_Init();
  MX_UART4_Init();
  MX_USB_PCD_Init();
  /* USER CODE BEGIN 2 */
  
  ButtonDriver_Init();
  DbgUart_Init();
  AddrLEDManager_Init();
  Geometry_Init();

  // Infinite loop v // TODO // refactor this test stuff
  logprint("Light Cube Initialized\n");
  AddrLEDManager_Workloop();
  //AddrLEDManager_RefreshTimerStart();
  /* USER CODE END 2 */

  /* Infinite loop */
  /* USER CODE BEGIN WHILE */
  while (1)
  {
    /* USER CODE END WHILE */

    /* USER CODE BEGIN 3 */
  }
  /* USER CODE END 3 */
}

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


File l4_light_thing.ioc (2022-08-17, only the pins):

Mcu.UserName=STM32L452RETx
PA0.Signal=S_TIM2_CH1
PA1.Signal=S_TIM2_CH2
PA10.Signal=I2C1_SDA
PA11.Signal=USB_DM
PA12.Signal=USB_DP
PA2.GPIO_Label=USART_TX
PA2.Signal=USART2_TX
PA3.GPIO_Label=USART_RX
PA3.Signal=USART2_RX
PA5.GPIO_Label=LD4 [green Led]
PA5.Signal=GPIO_Output
PA6.GPIO_Label=BATT_ADC_IN
PA6.Signal=ADCx_IN11
PA9.Signal=I2C1_SCL
PB0.Signal=ADCx_IN15
PB1.Signal=S_TIM3_CH4
PB10.Signal=S_TIM2_CH3
PB11.Signal=I2C2_SDA
PB13.Signal=I2C2_SCL
PB6.GPIO_Label=ACCEL_EXTI_0
PB6.Signal=GPIO_Input
PB7.GPIO_Label=ACCEL_EXTI_1
PB7.Signal=GPIO_Input
PC10.Signal=UART4_TX
PC11.Signal=UART4_RX
PC13.GPIO_Label=B1 [Blue PushButton]
PC13.Signal=GPXTI13
PC2.GPIO_Label=BT_GPIO_0
PC2.Signal=GPIO_Output
PC3.GPIO_Label=BT_GPIO_1
PC3.Signal=GPIO_Output
PC4.GPIO_Label=BT_GPIO_2
PC4.Signal=GPIO_Output
PC5.GPIO_Label=BT_GPIO_3
PC5.Signal=GPIO_Output
PC6.GPIO_Label=BATT_ADC_ENABLE
PC6.Signal=GPIO_Output
PC7.Signal=S_TIM3_CH2

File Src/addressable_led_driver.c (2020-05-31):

#include "addressable_led_driver.h"
#include "cmd_shell.h"
#include "main.h"
#include <string.h>
// Driver for the WS2812B based cascading, addressable LEDs

/*
 We have 5 different intervals, of which 4 must be followed accurately: T0H, T0L, T1H, T1L. Timings are reported on the datasheet as not strict (we have a margine of +-150ns) so that we can resume these intervals as:

 -Bit 0 1/3 of the period HIGH, 2/3 of the period LOW
 -Bit 1 2/3 of the period HIGH, 1/3 of the period LOW
 -Reset Stay LOW for at least 40 cycles (50us are about 40 periods of 1.25us)

Each WS2812B requires 24bits of data to reproduce a color. Each color is, in fact, composed of 3 groups of 8bits each that represent its RGB coding. This data must be sent following this order.

  GREEN[7:0] RED[7:0] BLUE[7:0]
*/

#define NAIVE_ADDR_LED_START_UPDATES() HAL_TIM_Base_Start_IT(&LED_PANEL_1_TIMER_HANDLE)
#define NAIVE_ADDR_LED_STOP_UPDATES()  HAL_TIM_Base_Stop_IT(&LED_PANEL_1_TIMER_HANDLE)

#define ADDR_LED_PWM_START()           HAL_TIM_PWM_Start(&LED_PANEL_1_PWM_TIMER_HANDLE, LED_PANEL_1_PWM_TIMER_CHANNEL);
#define ADDR_LED_PWM_STOP()            HAL_TIM_PWM_Stop(&LED_PANEL_1_PWM_TIMER_HANDLE, LED_PANEL_1_PWM_TIMER_CHANNEL);

#define ADDR_LED_PWM_SET_DUTY_CYCLE(d) __HAL_TIM_SET_COMPARE(&LED_PANEL_1_PWM_TIMER_HANDLE, LED_PANEL_1_PWM_TIMER_CHANNEL, d);

// PWM VALUES THAT MEET WS2812Bs SPECS
#define ADDR_LED_PWM_PSC 2
#define ADDR_LED_PWM_ARR 52//40//32

// PWM DUTY CYCLE VALUES FOR THE LOGIC HIGH AND LOW CODES
#define ADDR_LED_CODE_HIGH_COMPARE_VAL 23 
#define ADDR_LED_CODE_LOW_COMPARE_VAL  8

// PRIVATE VARIBLES -------------------------------------------------

uint32_t MICROSECOND_PRESCALER , MILLISECOND_PRESCALER;

// PRIVATE FUNCTIONS ------------------------------------------------

static void AddrLED_SetPWMPeriodUs(uint16_t ns)
{
  // Set/reset Symbol sending update timer to fire an interrupt
  // Stop and restart timer if it was already running
  bool tmrWasRunning = false;
  if (LED_PANEL_1_PWM_TIMER->CR1 ^ TIM_CR1_CEN)
  {
    tmrWasRunning = true;
    ADDR_LED_PWM_STOP();
  }

  // Update autoreload register
  // Timer will generate an IRQ every $ns nanoseconds
  LED_PANEL_1_PWM_TIMER->ARR = ns;

  // Generate update event to load new ARR immediately
  LED_PANEL_1_PWM_TIMER->EGR = TIM_EGR_UG;

  // Reset counter if timer was running before
  if (tmrWasRunning)
  {
    LED_PANEL_1_PWM_TIMER->CNT = 0x00;
    ADDR_LED_PWM_START();
  }
}

// WS2812B Related 

// Convert $byte into codes that WS2812B accepts, that we push out via PWM.
// 1 Byte converts into 8 bytes, so make sure $*codes pointer points to a block of memory that has 8 bytes allocated
static inline void ByteToCodes(uint8_t byte, uint8_t *codes)
{
  for (int b = 0; b < 8; b++)
  {
    codes[7-b] = ((byte & (0x1 << b)) > 0) ? ADDR_LED_CODE_HIGH_COMPARE_VAL : ADDR_LED_CODE_LOW_COMPARE_VAL;
  }
}

// Convert a Pixel_t object $p into codes that WS2812B accepts. 
// 1 Byte converts into 8 bytes, a Pixel_t is 3 bytes so make sure $*packet points to a block of memory that has 24 bytes allocated
static inline void PixelToPacket(Pixel_t *pixel, PixelPacket_t *packet)
{
  ByteToCodes(pixel->green, &(packet->greenRaw[0]));
  ByteToCodes(pixel->red, &(packet->redRaw[0]));
  ByteToCodes(pixel->blue, &(packet->blueRaw[0]));
}

// PUBLIC FUNCTIONS -------------------------------------------------

// Once the user creates an AddrLEDStrip_t object, they must set the fields of the structure themselves 
// and THEN pass that object here to be initialized
void AddrLED_Init(AddrLEDStrip_t *l)
{
  MICROSECOND_PRESCALER = ((HAL_RCC_GetSysClockFreq() / 1000000) - 1);    // 1000000 Hz
  MILLISECOND_PRESCALER = ((HAL_RCC_GetSysClockFreq() / 1000) - 1);       // 1000 Hz

  // ~ Initialize PWM Timer ~
  // Set update event flag so PSC and ARR are loaded
  l->pwmTimerHandle->Instance->PSC = ADDR_LED_PWM_PSC;
  l->pwmTimerHandle->Instance->ARR = ADDR_LED_PWM_ARR;
  l->pwmTimerHandle->Instance->EGR = TIM_EGR_UG;
}

// Take a whole strip structure and push out the pixels into the NeoPixels via DMA.
void AddrLED_DisplayStrip(AddrLEDStrip_t *l)
{
  PixelPacket_t *pixelPacketBufferPtr = (PixelPacket_t *) (l->pixelPacketBuffer);
  for (int i = 0; i < l->numLeds; i++)
  {
    Pixel_t *currPixel = &(l->pixels[i]);
    PixelPacket_t *currPixelPacket = pixelPacketBufferPtr + i;
    PixelToPacket(currPixel, currPixelPacket);
  }
  HAL_StatusTypeDef ret = HAL_TIM_PWM_Start_DMA(&LED_PANEL_1_PWM_TIMER_HANDLE, LED_PANEL_1_PWM_TIMER_CHANNEL, (uint32_t *) pixelPacketBufferPtr, l->numLeds * sizeof(PixelPacket_t) + 1);
  HAL_Delay(4);
  
  // We need to stop the pwm timer after our payload is sent and start it back up again
  AddrLED_StopPWM();
}

void AddrLED_SanityTest(AddrLEDStrip_t *l)
{
  //#define PWM_BASE_TEST
#define PWM_DMA_TEST

#ifdef PWM_BASE_TEST
  ADDR_LED_PWM_START();
  ADDR_LED_PWM_SET_DUTY_CYCLE(10);
  while(1){}
#endif
#ifdef PWM_DMA_TEST
#if 1

  PixelPacket_t *pixelPacketBufferPtr = (PixelPacket_t *) (l->pixelPacketBuffer);
  for (int i = 0; i < l->numLeds; i++)
  {
    Pixel_t *currPixel = &(l->pixels[i]);
    PixelPacket_t *currPixelPacket = pixelPacketBufferPtr + i;
    PixelToPacket(currPixel, currPixelPacket);
  }


#else
  const uint8_t dmaTestPayload[] = {ADDR_LED_CODE_HIGH_COMPARE_VAL, ADDR_LED_CODE_LOW_COMPARE_VAL, 1, 1, 1, 1, 0};
#endif
  HAL_StatusTypeDef ret = HAL_TIM_PWM_Start_DMA(&LED_PANEL_1_PWM_TIMER_HANDLE, LED_PANEL_1_PWM_TIMER_CHANNEL, (uint32_t *) pixelPacketBufferPtr, l->numLeds * sizeof(PixelPacket_t) + 1);
  //IDLE_FOREVER(100);
#endif
}

void AddrLED_StartPWM(void)
{
  ADDR_LED_PWM_START();
}

void AddrLED_StopPWM(void)
{
  ADDR_LED_PWM_STOP();
}

inline void AddrLED_SendReset(void)
{
  HAL_Delay(1);
}

// HMM this doesnt work. need to dma pwm this data
void AddrLED_NaiveISR(void)
{
  HAL_GPIO_TogglePin(DEBUG_PIN_GPIO_PORT, DEBUG_PIN_GPIO_PIN);
}

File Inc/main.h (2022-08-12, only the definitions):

#define B1_Pin GPIO_PIN_13
#define B1_GPIO_Port GPIOC
#define B1_EXTI_IRQn EXTI15_10_IRQn
#define BT_GPIO_0_Pin GPIO_PIN_2
#define BT_GPIO_0_GPIO_Port GPIOC
#define BT_GPIO_1_Pin GPIO_PIN_3
#define BT_GPIO_1_GPIO_Port GPIOC
#define USART_TX_Pin GPIO_PIN_2
#define USART_TX_GPIO_Port GPIOA
#define USART_RX_Pin GPIO_PIN_3
#define USART_RX_GPIO_Port GPIOA
#define LD4_Pin GPIO_PIN_5
#define LD4_GPIO_Port GPIOA
#define BATT_ADC_IN_Pin GPIO_PIN_6
#define BATT_ADC_IN_GPIO_Port GPIOA
#define BT_GPIO_2_Pin GPIO_PIN_4
#define BT_GPIO_2_GPIO_Port GPIOC
#define BT_GPIO_3_Pin GPIO_PIN_5
#define BT_GPIO_3_GPIO_Port GPIOC
#define BATT_ADC_ENABLE_Pin GPIO_PIN_6
#define BATT_ADC_ENABLE_GPIO_Port GPIOC
#define TMS_Pin GPIO_PIN_13
#define TMS_GPIO_Port GPIOA
#define TCK_Pin GPIO_PIN_14
#define TCK_GPIO_Port GPIOA
#define SWO_Pin GPIO_PIN_3
#define SWO_GPIO_Port GPIOB
#define ACCEL_EXTI_0_Pin GPIO_PIN_6
#define ACCEL_EXTI_0_GPIO_Port GPIOB
#define ACCEL_EXTI_1_Pin GPIO_PIN_7
#define ACCEL_EXTI_1_GPIO_Port GPIOB
#define CRITICAL_SECTION_BEGIN uint32_t p = __get_PRIMASK(); \
#define CRITICAL_SECTION_END   __set_PRIMASK(p);

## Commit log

2020-03-29 started working on timer1. 1 second frequency blinks
2020-03-30 pwm first pass
2020-04-02 led.c created
2020-05-02 updates. need to handle this in the timer/pwm
2020-05-03 PWM produces desired wave for the ws2818b
2020-05-03 PWM produces desired wave for the ws2818b. UPDATED
2020-05-03 struggling with dma
2020-05-04 the DMA issue not solved, but these ARR/CCR values _may_ be still good enough/among tolerance
    [addressable_led_driver.c]
2020-05-04 some progress. need to work on the LED IC's protocol
2020-05-05 arduino test added
2020-05-08 blackpill bricked. moving onto L4-disco board
2020-05-09 L4 able to light all LEDs just like the arduino. the problem was the LED strip not getting enough voltage
    [addressable_led_driver.c, sketch_may04a.ino]
2020-05-22 current draw survey code
2020-05-24 led flash problem solved
    [addressable_led_driver.c, addressable_led_manager.c]
2020-05-30 memory problem seems to be fixed wooo
    [addressable_led_driver.c, addressable_led_manager.c]
2020-06-05 kicad files added
    [light_thing_hw-2020-05-16-11-37-11.sch, light_thing_hw.kicad_pcb, light_thing_hw.sch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]
2020-06-07 updates on hw design. it seems like we can make it on a 3x3cm pcb. layout needs work
    [light_thing_hw.kicad_pcb, light_thing_hw.sch]
2020-06-13 hw updates
    [light_thing_hw.kicad_pcb, light_thing_hw.sch]
2020-06-21 made 5cm pcb. need to do routing etc.
    [light_thing_hw.kicad_pcb, light_thing_hw.sch]
2020-06-27 hw updates. sw initd new needed peripherals. some changes on pixel testbench
    [light_thing_hw.kicad_pcb]
2020-06-27 nucleo board needs work to enable uart. halting uart work until hardware arrives
2020-06-27 button handling begun
2020-06-28 software timers work
2020-06-28 button debounce done
2020-06-28 button debounce works. need to write button manager
2020-07-01 redone layout
    [light_thing_hw.kicad_pcb]
2020-07-07 gonna make the vvias now
    [light_thing_hw.kicad_pcb]
2020-07-07 about to do routing
    [light_thing_hw.kicad_pcb]
2020-07-07 placing modules
    [light_thing_hw.kicad_pcb]
2020-07-08 restarting routing
    [light_thing_hw.kicad_pcb, light_thing_hw.sch]
2020-07-08 doing well actually
    [light_thing_hw.kicad_pcb, light_thing_hw.sch]
2020-07-10 gonna add gnd now
    [light_thing_hw.kicad_pcb, light_thing_hw.sch]
2020-07-10 need to go thru drc
    [light_thing_hw.kicad_pcb]
2020-07-11 hw not lookin bad ngl
    [light_thing_hw-B.Cu.gbr, light_thing_hw-B.Mask.gbr, light_thing_hw-B.Paste.gbr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]
2020-07-12 added MIC_IN to hardware and in stmcube
    [light_thing_hw-B.Cu.gbr, light_thing_hw-B.Mask.gbr, light_thing_hw-B.Paste.gbr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]
2020-07-13 some sw changes. about to add another mosfet switch to the board for the mic
    [light_thing_hw.kicad_pcb, light_thing_hw.sch]
2020-07-19 randomtriangles fade up bug fixed
    [addressable_led_manager.c]
2020-07-19 about to change user button
    [light_thing_hw-B.Cu.gbr, light_thing_hw-B.Mask.gbr, light_thing_hw-B.Paste.gbr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]
2020-07-19 hw updates. sent to print
    [light_thing_hw-B.Cu.gbr, light_thing_hw-B.Mask.gbr, light_thing_hw-B.Paste.gbr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]
2020-08-12 about to redo hw for reordering
    [BLE_AND_ACCEL.sch, POWER.sch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]
2020-08-19 moved to STM32L476
    [light_thing_hw.kicad_pcb, light_thing_hw.sch]
2020-09-11 about to change diode footprint to something thats available in digikey
    [light_thing_hw.kicad_pcb, light_thing_hw.sch]
2020-10-04 picked new reset button and diode footprint
    [light_thing_hw.kicad_pcb, light_thing_hw.sch]
2020-10-30 original accel footprint brought back
    [light_thing_hw.kicad_pcb, light_thing_hw.sch]
2022-11-27 fixed button polarity setting and additions to dbg uart handling
    [addressable_led_manager.c, button_driver.c, button_driver.h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]
2022-11-27 added backspace to dbg uart

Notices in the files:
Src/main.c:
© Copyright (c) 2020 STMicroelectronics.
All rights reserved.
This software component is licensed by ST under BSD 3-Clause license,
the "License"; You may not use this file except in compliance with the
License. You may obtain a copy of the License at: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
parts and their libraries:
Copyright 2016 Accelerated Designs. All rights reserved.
